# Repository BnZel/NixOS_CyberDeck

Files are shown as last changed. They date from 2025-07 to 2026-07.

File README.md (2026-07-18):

# NixOS Cyberdeck 
A cyberdeck project based on the **Intel Compute Stick** that is running **NixOS**. 

I'm excited that it has been [featured](https://www.canadarobotix.com/blogs/news/customer-spotlight-bnzels-cyberdeck-journey-part-4) on a store where I purchase most of my electronics at [CanadaRobotix](https://www.canadarobotix.com/).

NixOS Cyberdeck Logo

## Tests
cyberdeck_demo

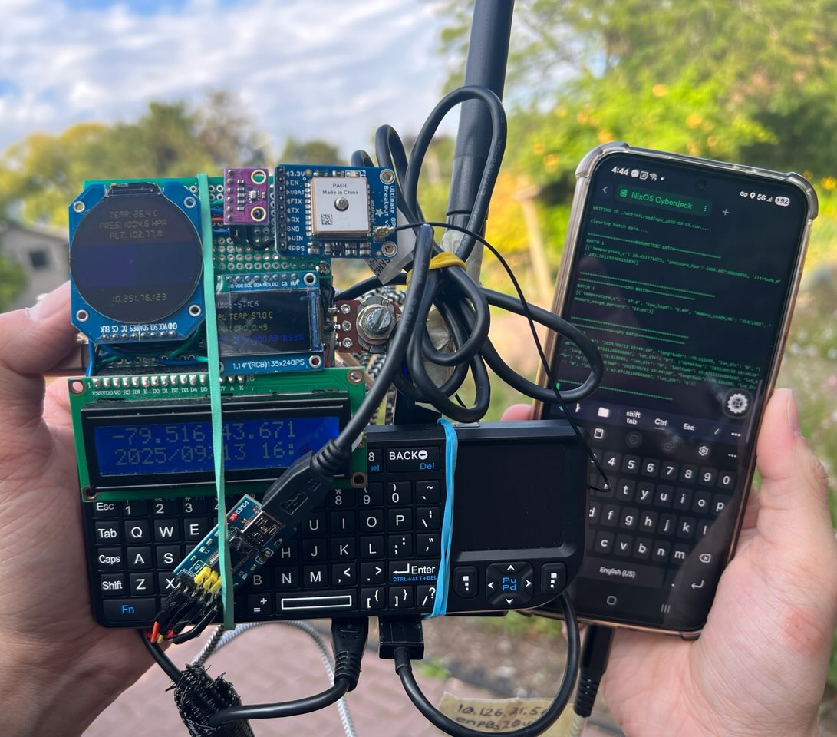
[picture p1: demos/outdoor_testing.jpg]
outdoor_testing


# Directory:
* [NixOS Database Analysis](./analysis/)
* [ESP32 Glove](./esp32_glove/)
* [Web Dashboard](./web_dashboard/)
* [Computer Aided Design](./cad/)

## Background

### Intel Compute Stick
The **[Intel Compute Stick (STK1AW32SC)](https://www.intel.com/content/www/us/en/products/sku/91065/intel-compute-stick-stk1aw32sc/specifications.html)** purpose was for media center applications, it has a convenient HDMI connector that can be directly plugged into any compatible monitor and TV.

Its main onboard specifications features:
* **4 CPU cores at 1.44 GHz**
* **32GB eMMC** and **2GB DDR3L-1600 RAM**
* **1 USB 2.0** and **1 USB 3.0** ports
* **MicroSDXC slot**

Although moderate in today standards, it is suitable enough for a *cyberdeck* based system.

### NixOS
The purpose of choosing **[NixOS](https://nixos.org/)** was because of its **reproducible system configurations** where it is easy to moveover to another machine. Allowing simple backups in scenarios where the cyberdeck were to encounter fatal issues.

The package manager makes it where the **build and development enviroments** can be properly separated and accessible without experiencing issues and interference with software tools. In my case, I can modify and/or activate environments based on what the cyberdeck needs to work on both hardware and software.

I have made several **blog posts** documenting my journey on the PC sticks:
1. [Discovering the Intel Compute Stick](https://bnzel.github.io/2024-08-03-Intel-Compute-Sticks/)
2. [Booting Ubuntu Server and NixOS onto the stick](https://bnzel.github.io/2024-08-07-ServerDeck-and-NixOS/)
3. [Breadboard prototyping the NixOS stick](https://bnzel.github.io/2025-04-07-NixOS-CyberDeck/)
4. [Latest iteration of the NixOS cyberdeck build](https://bnzel.github.io/2025-07-09-NixStick-Update/)

I list all software and hardware configurations, as well as documenting fixes issues too, though this README serves as a more thorough documentation. 

## Cyberdeck Introduction
This section will explain the *why?* and *how?* of my current build.

As I am limited by Intel's proprietary hardware, modifications are only on software tools, hardware addons, and the software written to run the hardware stack. 

### Hardware Addon

* **[Orico USB3.0 Hub with Gigabit Ethernet Converter](https://www.orico.shop/en/orico-usb30-hub-with-gigabit-ethernet-converter.html)** OR **[UNITEK H1117A02 4 Ports USB-A 3.0 Hub](https://www.canadacomputers.com/en/usb-hubs/260566/unitek-4-ports-usb-a-3-0-hub-h1117a02.html)** *(recommended as there is an external power supply to avoid pulling current from the deck itself)*
* **[Riitek Wireless Keyboard V3](http://www.riitek.com/product/221.html)**
* **USB Hub Voltage & Current Tester**
* **[AdaFruit FT232H (USB-C)](https://learn.adafruit.com/adafruit-ft232h-breakout)**
* **FTDI FT232RL USB to TTL adapter**

> At times the USB hub causes overvoltage and can crash the system when booting. Removing it before plugging it ensures a safe bootup. 

The **Orico USB hub** had conflicts between the ethernet port and the Intel's built-in wireless chip that created this issue:
```
iwlwifi 0000:01:00.0: Microcode SW error detected. Restarting 0x2000000
```
So in [configuration.nix](./configurations/configuration.nix):
```
  environment.etc."modprobe.d/iwlwifi.conf".text = ''
    options iwlwifi 11n_disable=1
    options iwlwifi power_save=0
  '';
```

There were other issues regarding the **5V/3A** adapter that I don't recall as I had to do alot of trial and error in **[hardware-configuration.nix](./configurations/hardware-configuration.nix)**:
```
boot.blacklistedKernelModules = ["i2c-designware-platform" "i2c-designware-core" "axp20x" "axp20x_i2c" "axp288_charger "];
```

### Architecture Overview
cyberdeck_architecture

### Custom Hardware
The **FT232H** is the main driver of the following components:
* **Displays**:
    * **GC9A01** (round display)
    * **ST7789** (square display)
    * **16x2 LCD** (rectangle display) and a **potentiometer** to adjust backlight
* **[BME280 (Barometric sensor)](https://www.bosch-sensortec.com/products/environmental-sensors/humidity-sensors-bme280/)**
* **[AdaFruit Ultimate GPS V3](https://learn.adafruit.com/adafruit-ultimate-gps)**
* **[74HC595 Shift Register](https://learn.adafruit.com/74hc595/overview)**

The **FTDI cable** is to power and receive serial communication with the **GPS**. The **GPS** provides a smooth **3.3V** to power the **BMP280** to avoid voltage spikes that may interfere the sensor accuracy.

The **BMP280** had encountered an error where the chip is not recognized. This was due to a **CS** pin issue from the **FT232H** that I was not able to pinpoint the reason. I switch it from **C7** to **D7**.

**GC9A01** is to display data from **BMP280**, **ST7789** to view the cyberdecks cpu: temperature, load, memory resource. The **LCD** shows date-time and **GPS** location. 

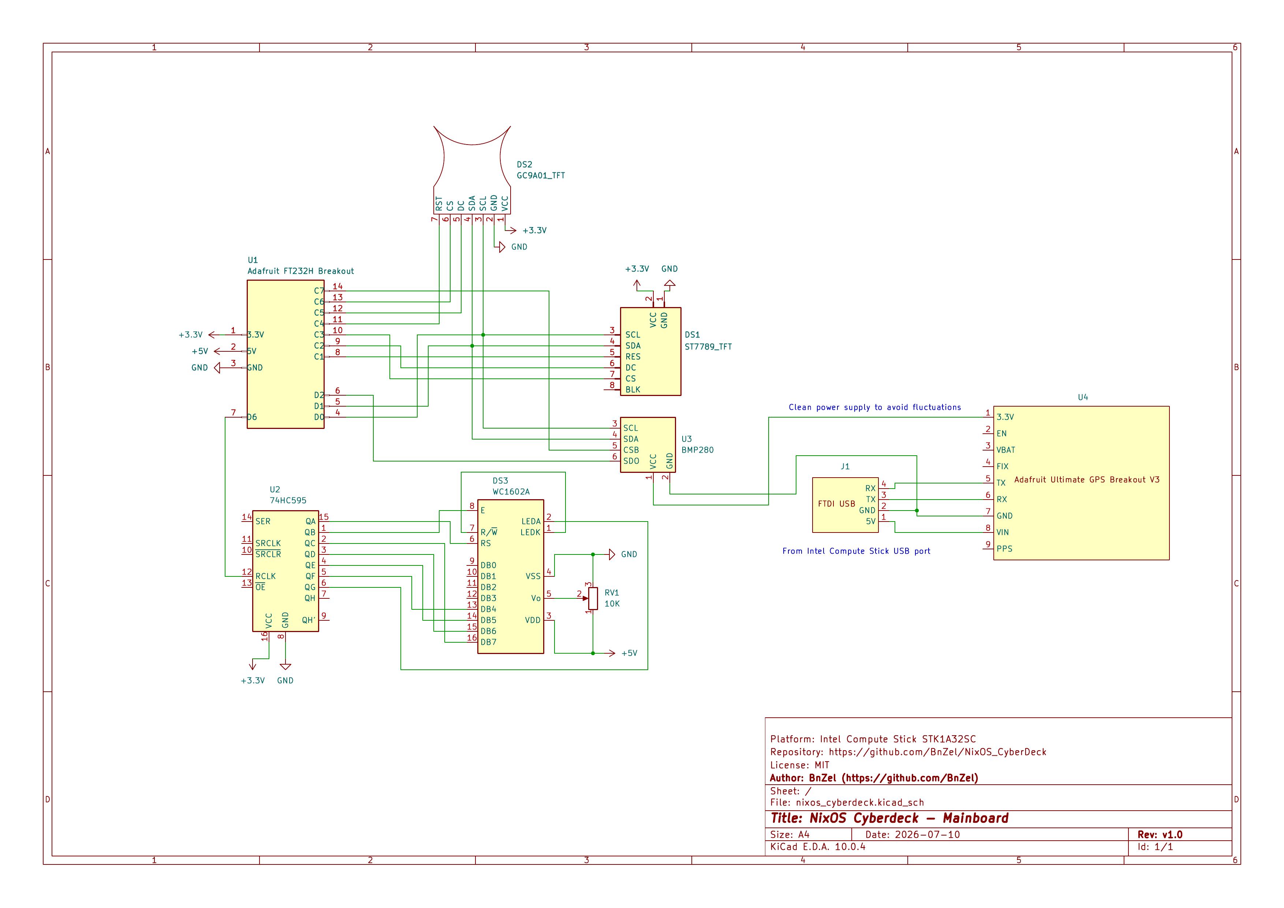
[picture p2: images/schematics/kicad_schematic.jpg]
kicad schematic
 

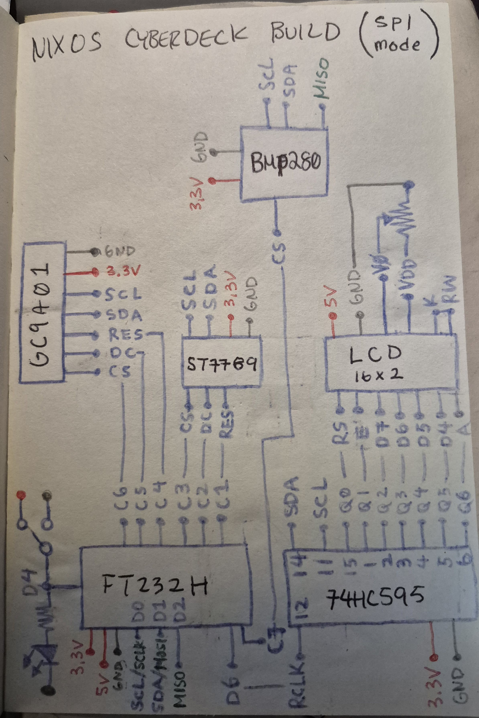
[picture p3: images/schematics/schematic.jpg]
schematic


A **SPST switch** in **D4** was suppose to be to activate a webcam stream but was not necessary for the moment.

In my blog post, I mentioned wanting a more compact design, so my approach was to make it stackable:

#### First Layer:
This were the FT232H sits, it will provide pins and **5V**, **3.3V**, **GND** pins to the second layer.

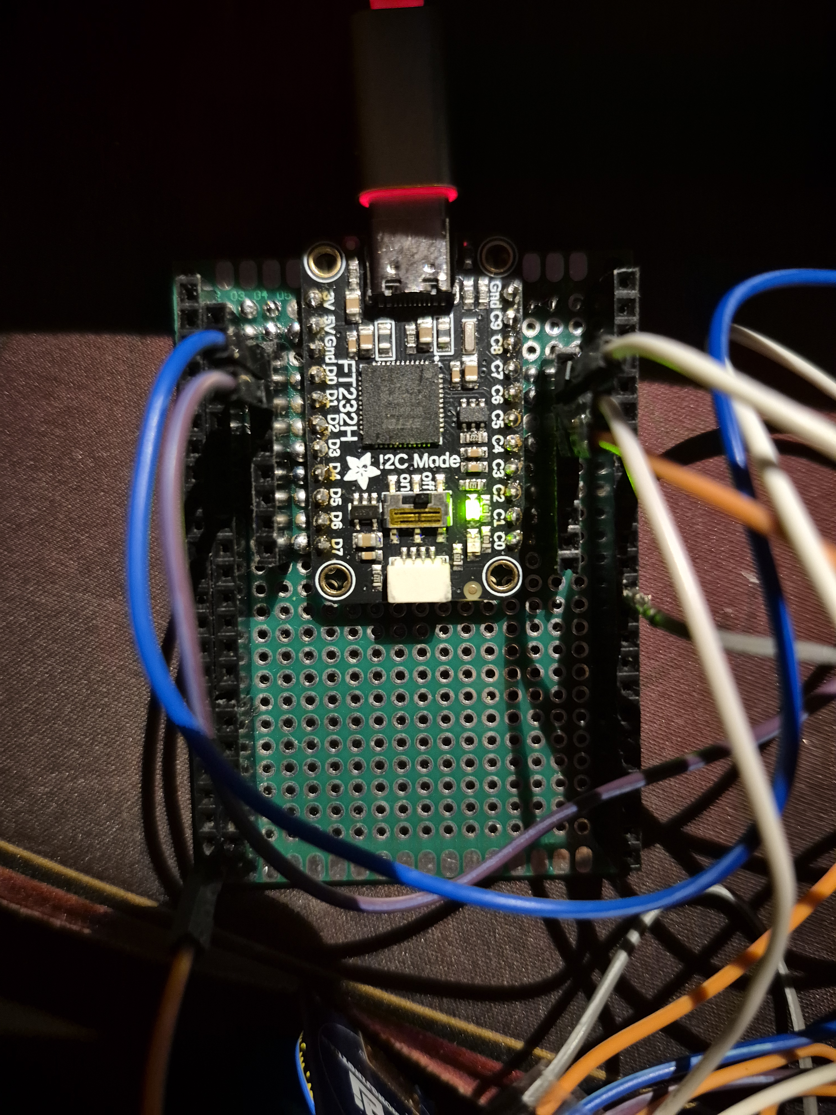
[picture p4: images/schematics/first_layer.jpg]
first layer


#### Second Layer:
All sensors and displays will sit here. There's another small protoboard above to give the BMP280 and GPS space.

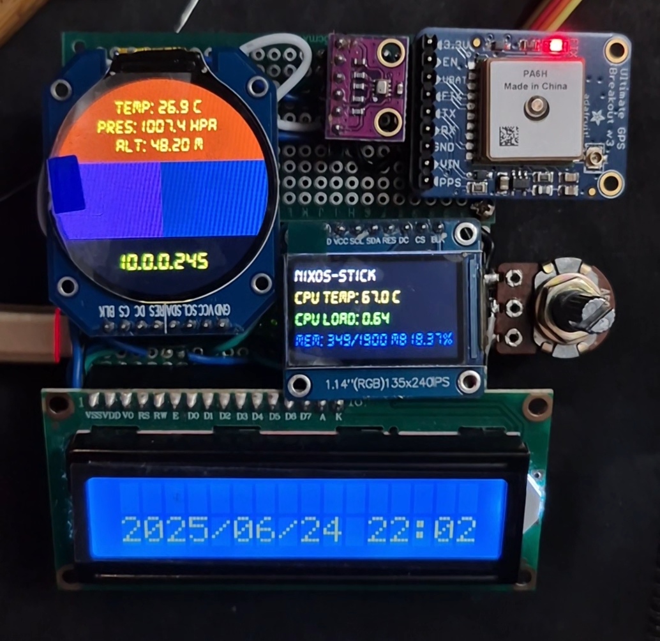
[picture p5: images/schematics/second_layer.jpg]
second layer


### Software
In the **[configurations.nix](./configurations/configuration.nix)** file:

Nix packages I use:
```
   environment.systemPackages = with pkgs; [
     wget
     htop
     fastfetch
     zsh
     oh-my-zsh
     git
     linux-firmware
     linux-wifi-hotspot
     tmux
     busybox
     cockpit
     libusb1
   ];
```
My mostly used tools are **zsh** for its autocomplete and highlighting features, **cockpit (runs on port 9090)** for a more graphical approach to my headless setup and to view system health, and **tmux** to view dmesg logs and starting scripts within one terminal.

Creating a separate Python environment in NixOS is different from other Linux distros, I came across this **[template](https://github.com/NixOS/nixpkgs/blob/49829a9adedc4d2c1581cc9a4294ecdbff32d993/doc/languages-frameworks/python.section.md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)** from their official **[Github](https://github.com/NixOS)** that I **[modified](./configurations/default.nix)**.

**OpenCV** was not used but can be useful for linking important **cpp .so** files:
```
LD_LIBRARY_PATH = lib.makeLibraryPath [ pkgs.stdenv.cc.cc ];
```
Addtional packages for the environment. **screen** to view serial data, **gcc** to compile C/C++ files for potential projects, **pkg-config** if linking more object files are needed:
```
packages = [ pkgs.screen pkgs.gcc pkgs.gnumake pkgs.pkg-config pkgs.openssl ];
```

[sanity_test.py](./software/sanity_test.py) is to check whether both the FT232H and FTDI cables are properly connected. Troubleshooting that first avoids assuming a USB hub issue.

FT232H runs on **[Adafruit_Blinka](https://github.com/adafruit/Adafruit_Blinka)** and at the moment, **adafruit-blinka** is not on nixpkgs so [requirements.txt](./software/requirements.txt) will do. Libraries for 75HC595 shift register, processing serial data for the FTDI, and displays will also be in the txt file.

#### [Custom Hardware Driver](./software/main.py)
```python

import board
from board import SCK, MOSI, MISO

import busio
import digitalio
from adafruit_rgb_display.st7789 import ST7789
from PIL import Image, ImageDraw, ImageFont

from adafruit_rgb_display.gc9a01a import GC9A01A

import adafruit_bmp280

import numpy as np
import cv2 as cv
import asyncio
import os

import time
import subprocess

import adafruit_character_lcd.character_lcd as character_lcd
import adafruit_74hc595

import wws_74hc165

import serial
import usb.core
import sys
import pynmea2
import datetime
import random

spi = busio.SPI(clock=SCK, MOSI=MOSI, MISO=MISO)

def init_display(disp,cs,dc,reset,rotate,w,h,x_off,y_off,BAUDRATE=24000000):
    CS_PIN = cs
    DC_PIN = dc
    RESET_PIN = reset
    display = disp(
        spi,
        rotation=rotate,
        width=w,
        height=h,
        x_offset=x_off,
        y_offset=y_off,
        baudrate=BAUDRATE,
        cs=digitalio.DigitalInOut(CS_PIN),
        dc=digitalio.DigitalInOut(DC_PIN),
        rst=digitalio.DigitalInOut(RESET_PIN)
    )
    return display

def rotation(display):
    height=0
    width=0
    if display.rotation % 180 == 90:
        height = display.width  # swap height/width to rotate it to landscape
        width = display.height
    else:
        width = display.width  # swap height/width to rotate it to landscape
        height = display.height

    return height, width

def draw_image(disp,width,height,fill=0):
    disp.fill(0)
    disp_image = Image.new("RGB", (width,height))
    disp_draw = ImageDraw.Draw(disp_image)

    return disp_image, disp_draw

async def bmp280_task():
#    if btn_toggle.value is False:
        gca_draw.rectangle((0, 0, disp_gc9a01.width, disp_gc9a01.height // 2 - 30), fill=(155, 50, 0))
        gca_txt_bmp_temp = "    Temp: {:.1f} C".format(bmp280.temperature) + "\nPres: {:.1f} hPa".format(bmp280.pressure) + "\n    Alt: {:.2f} M".format(bmp280.altitude)
        gca_draw.text(
            (disp_gc9a01.width // 2 - 70 , disp_gc9a01.height // 2 - 100),
            gca_txt_bmp_temp,
            font=gca_bmp_font,
            fill=(255, 255, 0),
        )
#        gca_draw.text(
#	    (disp_gc9a01.width//2-70, disp_gc9a01.height//2-100),
#	    f"{random.randint(0,100)}",
#	    font=gca_font,
#            fill=(255,255,0),
#        )
        disp_gc9a01.image(gca_image)

async def cam_task():
    if btn_toggle.value is True:
        ret,frame = cap.read()

        if not ret:
            print("Can't receive frame (stream end?). Exiting...")
            os._exit(1)

        resize = cv.resize(frame, (disp_gc9a01.width, disp_gc9a01.height), interpolation=cv.INTER_AREA)
        rgb = cv.cvtColor(resize, cv.COLOR_BGR2RGB)
        pil = Image.fromarray(rgb)
        disp_gc9a01.image(pil)

async def async_main():
   # await asyncio.gather(bmp280_task(),cpu_task(),cam_task(),gps_task())
   await asyncio.gather(bmp280_task(),cpu_task(),gps_task())

async def cpu_task():
    st7789_draw.rectangle((0, 0, width, height), outline=0, fill=0)

    # REFERENCE: https://unix.stackexchange.com/questions/119126/command-to-display-memory-usage-disk-usage-and-cpu-load
    hostname = subprocess.check_output("hostname",shell=True).decode("utf-8")
    cpu_temp = subprocess.check_output("cat /sys/class/thermal/thermal_zone1/temp |  awk '{printf \"CPU Temp: %.1f C\", $(NF-0) / 1000}'",shell=True).decode("utf-8")
    cpu_load = subprocess.check_output("top -bn1 | grep load | awk '{printf \"CPU Load: %.2f\", $(NF-2)}'",shell=True).decode("utf-8")
    mem = subprocess.check_output("free -m | awk 'NR==2{printf \"Mem: %s/%s MB %.2f%%\", $3,$2,$3*100/$2 }'",shell=True).decode("utf-8")

    st7789_draw.text((x,y+10),hostname,font=st7789_font, fill="#FFFFFF")
    st7789_draw.text((x,y+40),cpu_temp,font=st7789_font, fill="#FFFF00")
    st7789_draw.text((x,y+70),cpu_load,font=st7789_font, fill="#00FF00")
    st7789_draw.text((x,y+100),mem,font=st7789_font, fill="#000FF0")

    # display it by 90 deg
    disp_st7789.image(st7789_image)

async def gps_task():

#    lcd.message = "Hello World!"
#    print(lcd.message)

    # TODO: Find a way to retrieve FTDI name, locate the port
    #       and use that. Check if it is open, otherwise continue 
    with serial.Serial("/dev/ttyUSB1", 9600, timeout=1) as ser:

        data = ser.readline().decode('ascii', errors='replace')
        dt = datetime.datetime.now().strftime("%Y/%m/%d %H:%M")

        if(data[0:6] == "$GPRMC"):
            lcd.clear()

            gps_data = pynmea2.parse(data)

            lon = gps_data.longitude
            lat = gps_data.latitude

            lcd.message = "Lon:{0} Lat:{1}".format(lon,lat)
            print(lcd.message)

        lcd.message = "\n{0}".format(dt)

if __name__ == "__main__":
    # REMINDER: THIS SCRIPT IS IN ONLY SPI MODE!
    #           (SINCE THE FT232H UART/MPSSE OPERATES IN ONE SPECIFIC MODE)

    # -----74HC165 IS INPUT ONLY-----
    #_74hc165_isr_latch = board.D5
    #_74hc165_isr = wws_74hc165.ShiftRegister74HC165(spi, _74hc165_isr_latch, 1)

    # -----74HC595 IS OUTPUT ONLY-----
    _74hc595_isr_latch = digitalio.DigitalInOut(board.D6)
    _74hc595_isr = adafruit_74hc595.ShiftRegister74HC595(spi, _74hc595_isr_latch, 1)

    # connecting LCD to 74HC595 
    lcd_rs = _74hc595_isr.get_pin(0)
    lcd_en = _74hc595_isr.get_pin(1)
    lcd_d7 = _74hc595_isr.get_pin(2)
    lcd_d6 = _74hc595_isr.get_pin(3)
    lcd_d5 = _74hc595_isr.get_pin(4)
    lcd_d4 = _74hc595_isr.get_pin(5)

    lcd_backlight = _74hc595_isr.get_pin(6)

    lcd_columns = 16
    lcd_rows = 2

    lcd = character_lcd.Character_LCD_Mono(lcd_rs, lcd_en, lcd_d4, lcd_d5, lcd_d6, lcd_d7, lcd_columns, lcd_rows, lcd_backlight)
    lcd_backlight.value = True
    lcd.message = "BOOTING\nUP..."

    # clear old outputs for incoming ones
    subprocess.run(["clear"])

    # switch for camera mode for round display
#    btn_toggle = digitalio.DigitalInOut(board.D4)
#    btn_toggle.direction = digitalio.Direction.INPUT

    # list connected USB devices
    print("ls /dev/video* : ",subprocess.check_output("ls /dev/video* | grep -oP '/dev/video\d+' | tr '\n' ' ' | sed 's/ $//'",shell=True))
    print("ls /dev/ttyUSB* : ",subprocess.check_output("ls /dev/ttyUSB* | grep -oP '/dev/ttyUSB\d+' | tr '\n' ' ' | sed 's/ $//'",shell=True))

    # camera check
#    cap = cv.VideoCapture(-1)
#    if not cap.isOpened():
#        print("Cannot open camera...")
#    cap.set(cv.CAP_PROP_FPS,30)

    # barometer setup for round display
    bmp280_cs = digitalio.DigitalInOut(board.D7)
    bmp280 = adafruit_bmp280.Adafruit_BMP280_SPI(spi, bmp280_cs)
    bmp280.sea_level_pressure = 1017.0
    gca_bmp_font = ImageFont.truetype('./DS-DIGIT.TTF',20)

    # ----------------set up round display ----------------
    disp_gc9a01 = init_display(GC9A01A,board.C6,board.C5,board.C4,180,240,240,0,0)
    gca_image, gca_draw = draw_image(disp_gc9a01,disp_gc9a01.width,disp_gc9a01.height)

    gca_draw.rectangle((0, 0, disp_gc9a01.width, disp_gc9a01.height // 2 - 30), fill=(155, 50, 0))                          # upper rectangle
    gca_draw.rectangle((0, 90, disp_gc9a01.width // 2, disp_gc9a01.height // 10 + 150), fill=(105, 50, 150))                # left rectangle
    gca_draw.rectangle((120, 90, disp_gc9a01.width // 2 + 150, disp_gc9a01.height // 10 + 150), fill=(10, 50, 100))         # right rectangle

    gca_font = ImageFont.truetype('./DS-DIGIT.TTF',25)
    gca_txt_ip = subprocess.check_output("ip -4 addr | grep -oP '(?<=inet\s)\d+(\.\d+){3}' | grep -v '127\.0\.0\.1'",shell=True).decode("utf-8")
    gca_draw.text(
        (disp_gc9a01.width // 2 - 50 , disp_gc9a01.height // 2 + 70),
        gca_txt_ip,
        font=gca_font,
        fill=(255, 255, 0),
    )
    disp_gc9a01.image(gca_image)
    # ------------------------------------------------------

    # ---------------- set up tft display ----------------
    x = 0
    y = -2
    disp_st7789 = init_display(ST7789,board.C3,board.C2,board.C1,90,135,240,53,40)
    height,width = rotation(disp_st7789)
    st7789_image, st7789_draw = draw_image(disp_st7789,width,height)
    st7789_font = ImageFont.truetype('./DS-DIGIT.TTF',23)
    # ------------------------------------------------------

    lcd.clear()

    # gracefully exit when CTRL+C
    try:
        while True:
            asyncio.run(async_main())

    # offload camera, lcd, and exit
    except KeyboardInterrupt:
 #       cap.release()
        lcd.clear()
        lcd.backlight = False
        os._exit(1)
        print("\nCancelled...")
```

## Latest Setup

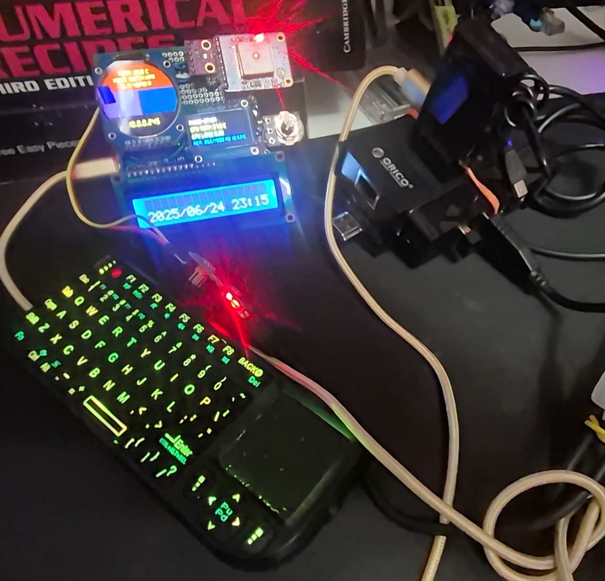
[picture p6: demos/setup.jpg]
setup


case setup

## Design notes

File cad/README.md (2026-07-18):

# Hardware Designs

A reference page to document iterations of **schematic**, **PCB** and **CAD** designs. 

Tools used are **[KiCAD](https://www.kicad.org/)** and **[FreeCAD](https://www.freecad.org/)**

### [Version 1](./v1/)
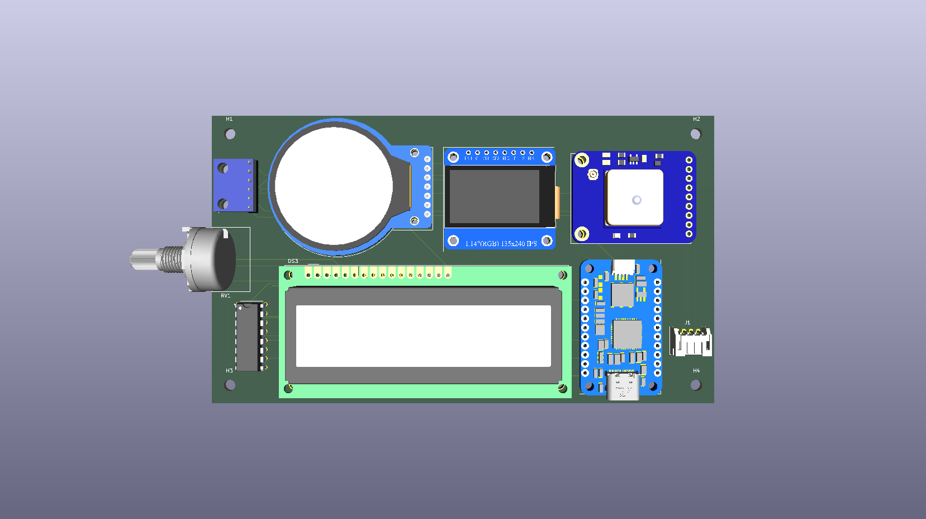
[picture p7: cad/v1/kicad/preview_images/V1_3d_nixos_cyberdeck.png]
preview model


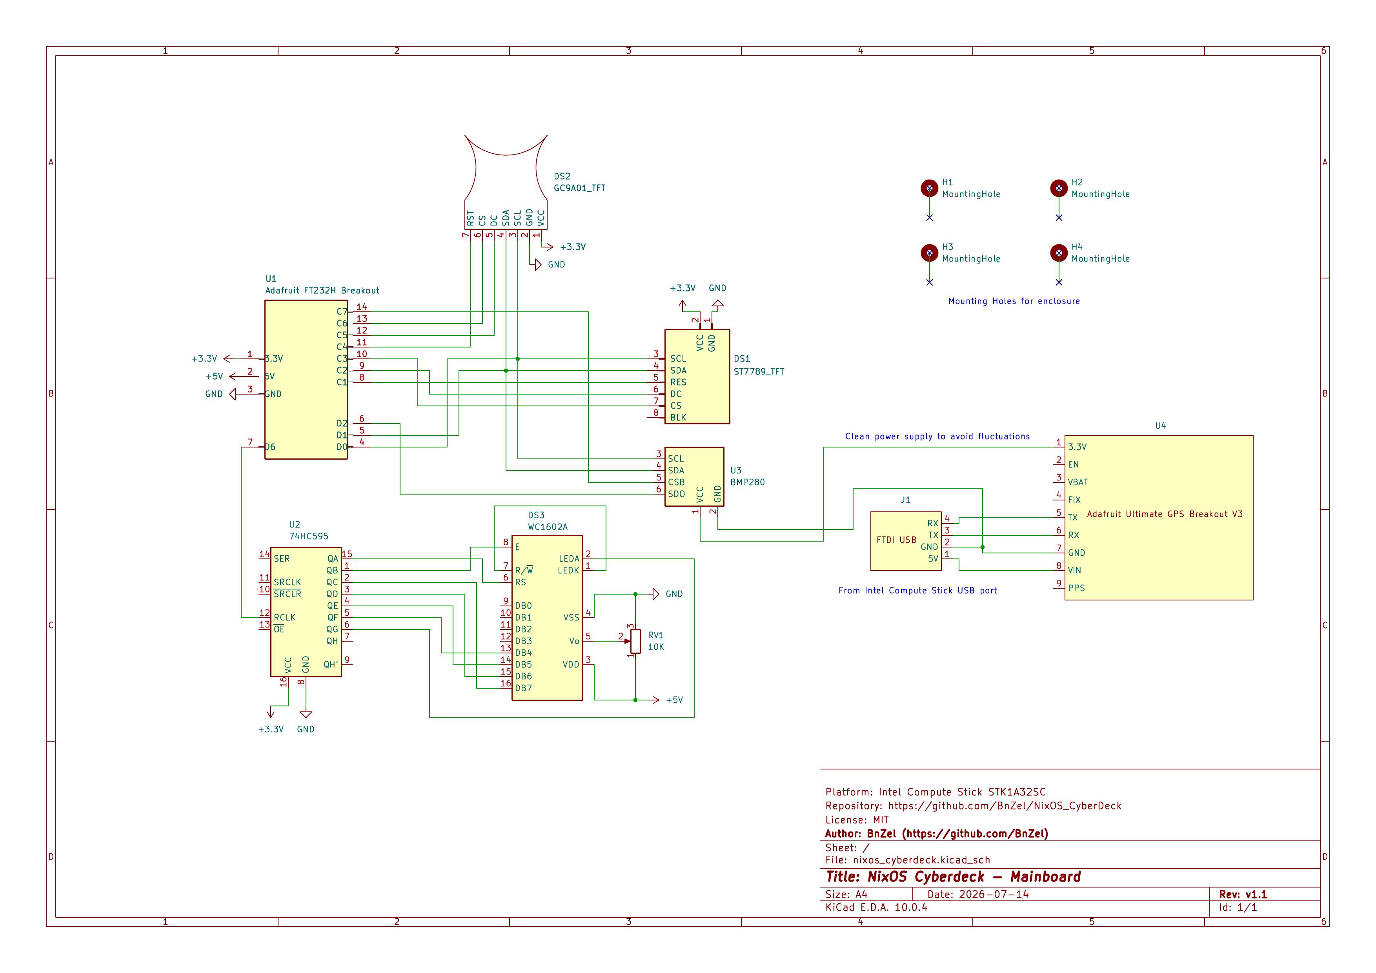
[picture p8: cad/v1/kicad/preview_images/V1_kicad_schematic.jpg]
preview schematic


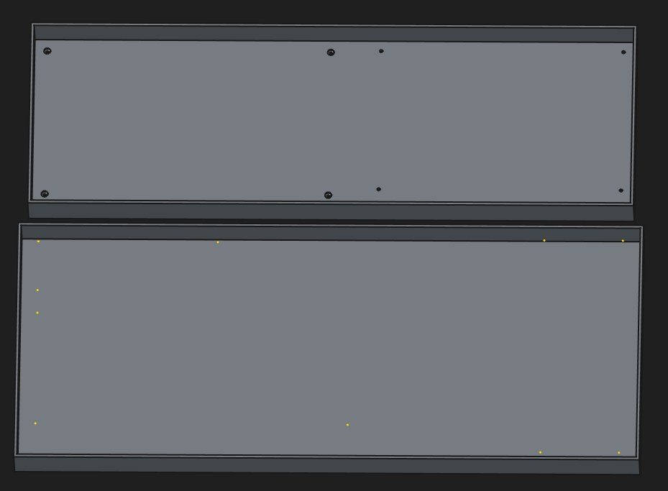
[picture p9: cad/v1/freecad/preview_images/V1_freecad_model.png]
preview case


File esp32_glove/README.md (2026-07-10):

# ESP32 Glove

A custom sensor glove based on the [Adafruit ESP32 Feather Huzzah](https://learn.adafruit.com/adafruit-huzzah32-esp32-feather?view=all) that is connected to the cyberdecks TCP server. It is programmed in **[MicroPython](https://micropython.org/)**.

The glove is based on the [Potentiometer Glove Model](https://www.thingiverse.com/thing:2782111) on Thingiverse.

I have made posts on my blog documenting my two iterations of the glove:
* [Sensor Glove V1](https://bnzel.github.io/2024-11-13-Crude-Sensor-Glove/)
* [Sensor Glove V2](https://bnzel.github.io/2025-07-10-Sensor-Glove-V2/)

### Demo
esp32 demo

### Hardware
* **[Adafruit ESP32 Feather Huzzah](https://learn.adafruit.com/adafruit-huzzah32-esp32-feather?view=all)**
* **[Potentiometer Glove Model](https://www.thingiverse.com/thing:2782111)**
* **1.3" I2C OLED (SSD1306)**
* **MPU9250**
* **5x Rotary Potentiometers**

### Software
#### Libraries:
* [SSD1306 Library](https://github.com/Eivs/micropython-ssd1306-oled-1.3-drivers)
* [MPU9250 Library](https://github.com/tuupola/micropython-mpu9250)
#### Code
* **[Firmware](./firmware/)**
* **[TCP Server in C](./glove_server/)**

### Resources
* [map() function in Arduino](https://docs.arduino.cc/language-reference/en/functions/math/map/)
* [Exponential Smoothing](https://en.wikipedia.org/wiki/Exponential_smoothing)

### Diagram 
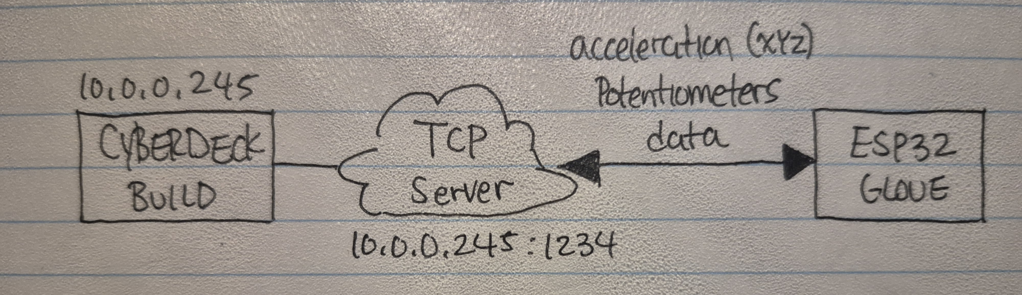
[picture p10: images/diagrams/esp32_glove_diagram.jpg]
diagram

*this is part of the [cyberdeck architecture diagram](../images/diagrams/cyberdeck_architecture.jpg)*
### Schematic
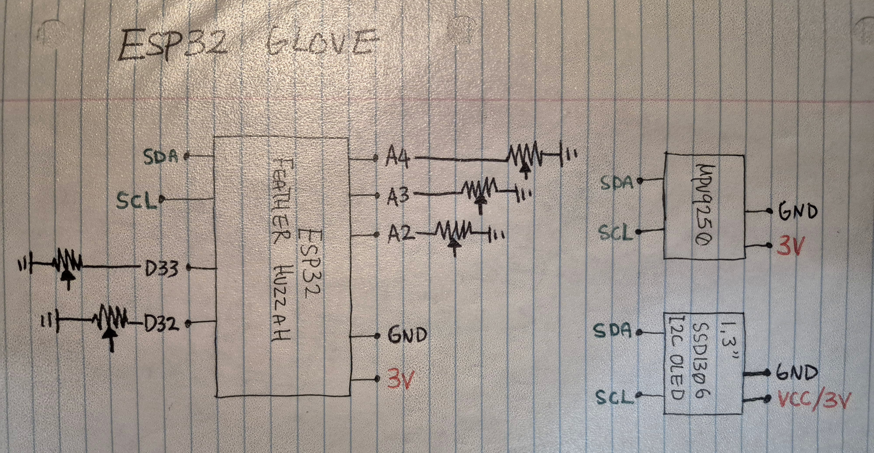
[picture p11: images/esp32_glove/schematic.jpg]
schematic


### Sketch
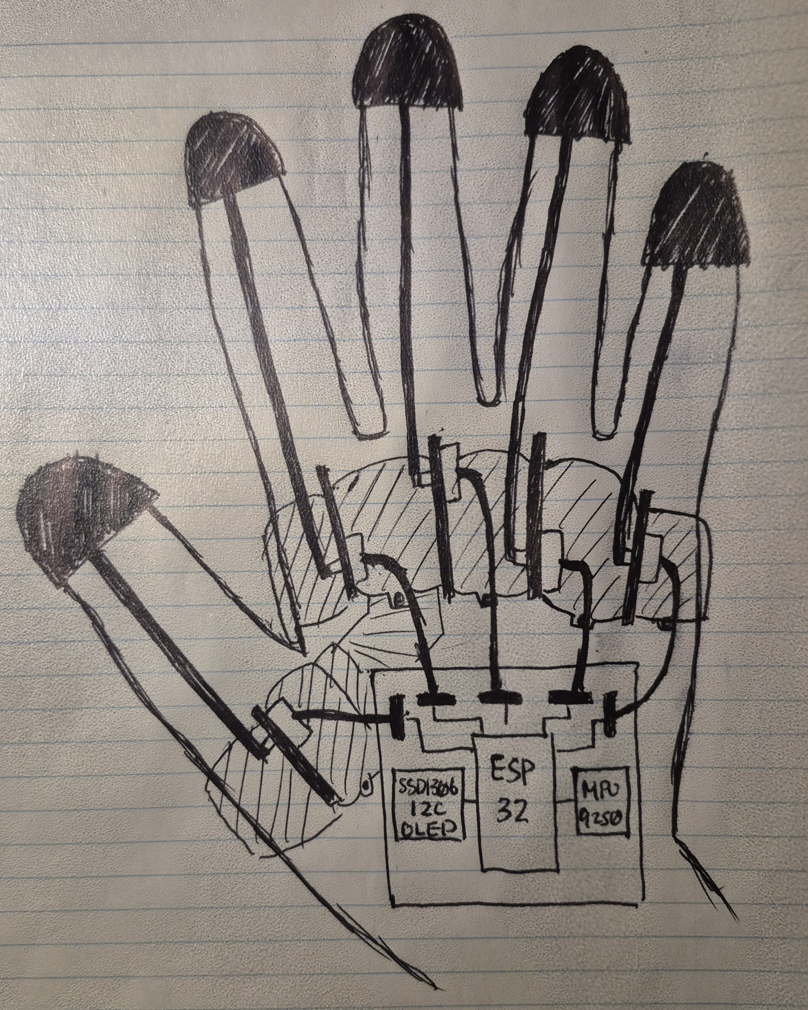
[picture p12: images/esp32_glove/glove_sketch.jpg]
sketch


### Formulas

#### Affine Transformation
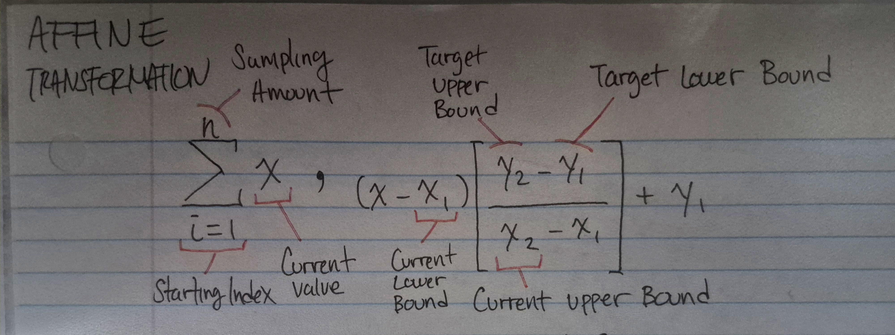
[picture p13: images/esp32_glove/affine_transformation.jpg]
affine


```python
def map_(adc_pin, id, from_low=0, from_high=0, to_low=0, to_high=0, sample=24, smooth=False):
    x_ = adc_pin.read()
    if from_high == 0 and to_high == 0:
        return x_
    else:
        if sample > 1:
            sum_ = 0
            for i in range(sample):
                sum_ += adc_pin.read()
            x_ = sum_ // sample
        
        # NOTE: unusual behaviour where some readings
        #       slowly reduce and others do not respond
        if smooth:
            if id not in pot_ID:
                pot_ID[id] = x_
            x_ = smoothing(x_, pot_ID[id])
            pot_ID[id] = x_

    z = (x_ - from_low) * (to_high - to_low) // (from_high - from_low) + to_low 
    return z
```

#### Exponential Smoothing
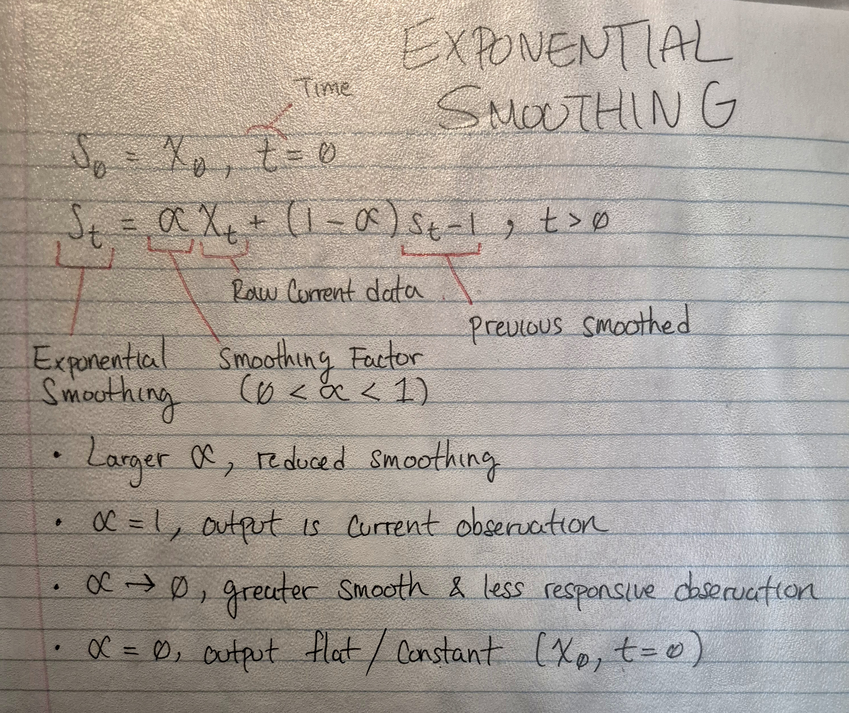
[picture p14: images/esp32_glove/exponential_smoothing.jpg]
exponential

```python
def smoothing(s0, prev_s_t, alpha=0.1):
    # 0 < alpha < 1
    if alpha >= 0 and alpha <= 1:
        prev_s_t = alpha * s0 + (1-alpha) * prev_s_t
        return int(prev_s_t)
    return s0
```
### Applications
* ### [Servo Controller](./servo_controller/)
A demo showcasing remote control of servos. 

servo controller demo

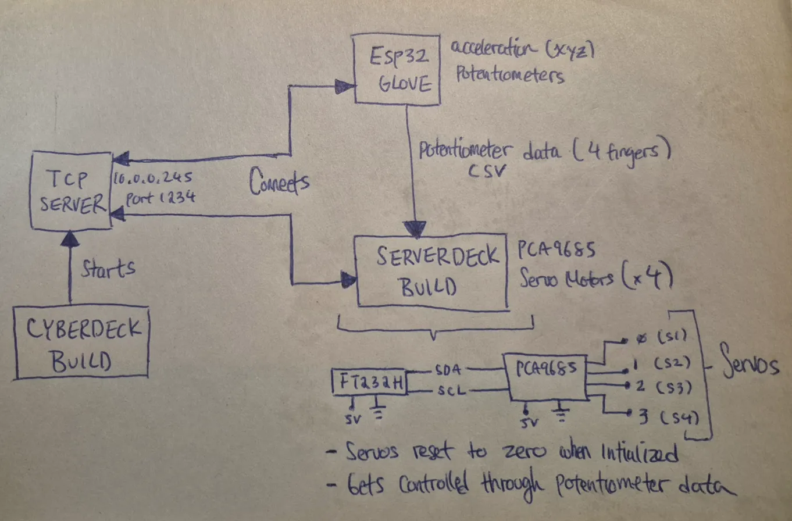
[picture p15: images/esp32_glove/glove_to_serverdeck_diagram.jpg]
glove to serverdeck diagram


The **[SERVERDECK BUILD](https://bnzel.github.io/2024-08-07-ServerDeck-and-NixOS/)** block refers to my very first cyberdeck build but this can be interchangable with any client.

### Software
* **[main.py](./servo_controller/main.py)**
* **[requirements.txt](./servo_controller/requirements.txt)**

### Hardware
* **PCA9685**
* **DC Servo Motors (x4)**

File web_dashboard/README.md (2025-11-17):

# Web Dashboard
A remote dashboard that runs the startup script on the cyberdeck and displays sensor data 

> startup script is different from main as it does not log data and sends JSON data to the dashboard

Using a **ThinkCentre M700** running **[Proxmox VE](https://www.proxmox.com/en/)**. An **LXC container** running **Ubuntu 25.04 with 2GB memory and 1GB swap**

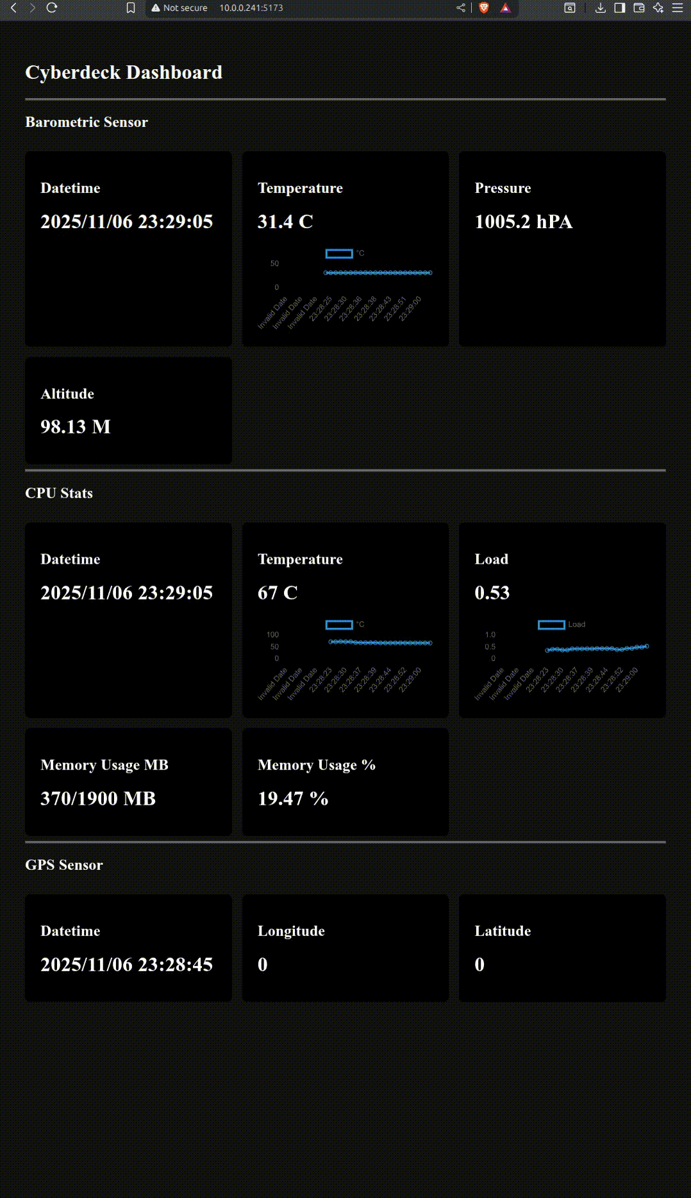
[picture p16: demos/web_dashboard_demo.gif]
dashboard


### Resources
* **[Svelte and Flask Dashboard Tutorial](https://testdriven.io/blog/flask-svelte/)**
* **[Paramiko Python SSH Tutorial](https://www.devdungeon.com/content/python-ssh-tutorial#toc-3)**

### Software
* **[Proxmox](https://www.proxmox.com/en/)**
* **[Test Script](./test.py)**
* **[Frontend](./frontend)**
* **[Backend](./backend)**

#### Frontend
* **[Svelte](https://svelte.dev/)**
* **SvelteKit**

#### Backend
* **[Flask](https://flask.palletsprojects.com/en/stable/)**
* **JSON**
* **[Paramiko](https://www.paramiko.org/)**

### Hardware
* **Lenovo ThinkCentre M700**

### Diagrams

#### Proxmox Web Directory
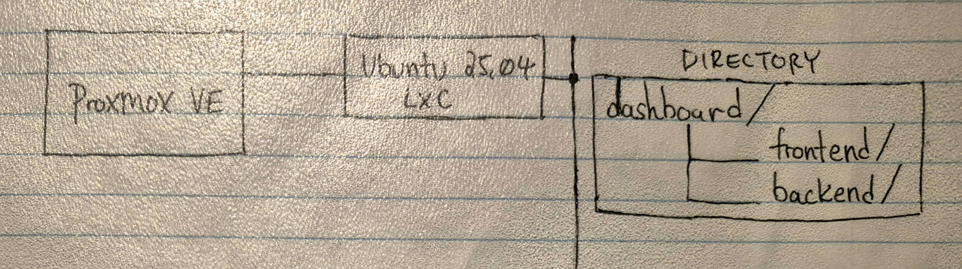
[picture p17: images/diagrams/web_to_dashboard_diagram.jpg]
web to cybedeck


#### How Proxmox Interacts With The Cyberdeck
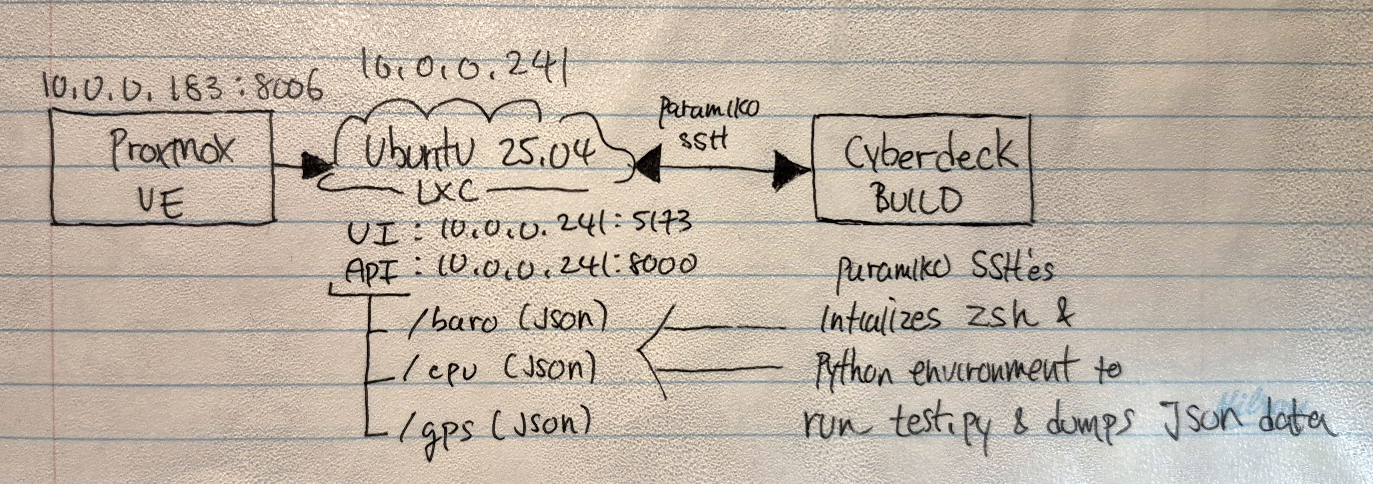
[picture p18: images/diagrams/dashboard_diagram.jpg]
dashboard


### Startup
```
cd web_dashboard/
npm install
npm run dev  
```

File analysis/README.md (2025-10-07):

# NixOS Database Analysis
This is a separate **Intel Compute Stick** to perform data analysis on the [NixOS Cyberdeck](../README.md). The purpose is to have a **portable embedded database** to store and process data (CPU, GPS, Barometric sensors). While this setup can be installed on the same device it's best to differentiate the task to avoid confusion and overhead.

## Overview
nixexp_architecture

## Setup
* **[analysis.ipynb](./analysis.ipynb)**
* **cyberdeck.db**
* **[default.nix](./default.nix)**
* **[requirements.txt](./requirements.txt)**

In **default.nix** the following packages will be installed:
```
    # main data analysis tools
    pythonPackages.pandas
    pythonPackages.matplotlib
    pythonPackages.numpy
    pythonPackages.requests

    # optional but recommended
    packages = [ pkgs.screen pkgs.gcc pkgs.gnumake pkgs.pkg-config pkgs.openssl ];

    # needed to load jupyter notebook server
    LD_LIBRARY_PATH = lib.makeLibraryPath [ pkgs.stdenv.cc.cc ];
```
> The Jupyter NixOS package currently has issues, a post made in this [github issue](https://github.com/NixOS/nixpkgs/issues/255923) suggested to use the pip environment to install Jupyter. 

Python packages that aren't avaliable in Nix packages can be installed through ```pip install -r requirements.txt```:
* **GPS:** **[Geopandas](https://geopandas.org/en/stable/)** and related libraries
* **[DuckDB](https://duckdb.org/)**

### **DuckDB**:
Tables are already made for each hardware component.

#### Tables
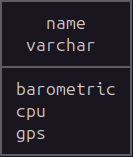
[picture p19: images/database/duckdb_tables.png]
duckdb_tables


#### Barometric Table
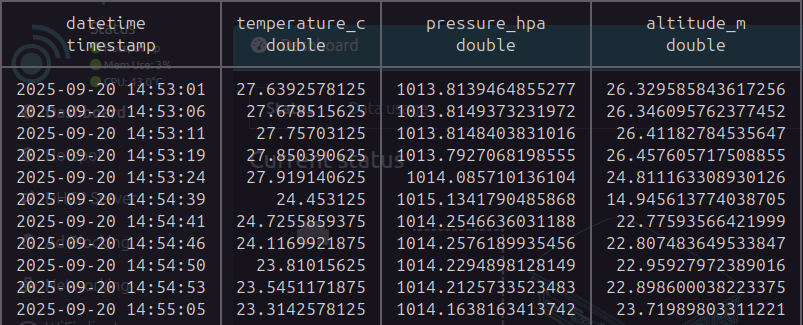
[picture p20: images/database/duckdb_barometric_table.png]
duckdb_barometric


#### CPU Table
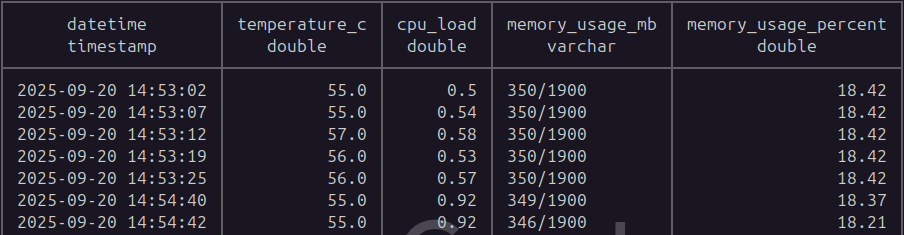
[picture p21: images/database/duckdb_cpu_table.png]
duckdb_cpu


#### GPS Table
Filtered for values that aren't non-zeroes. **SPATIAL** extension is needed to display the **lon_lat_geometry** column.
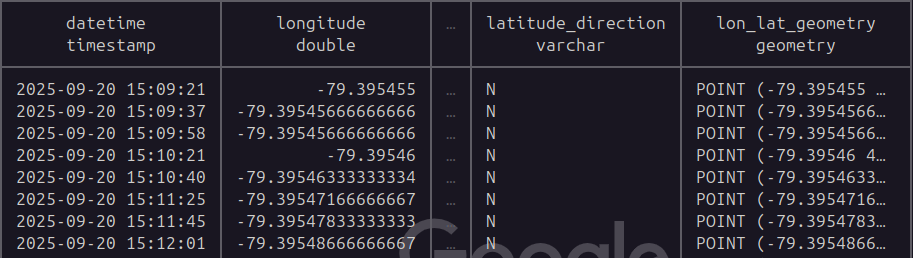
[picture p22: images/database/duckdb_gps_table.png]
duckdb_gps


### **Jupyter Notebook**
Can be used as reference.
### Geopandas
GPS points being plotted 

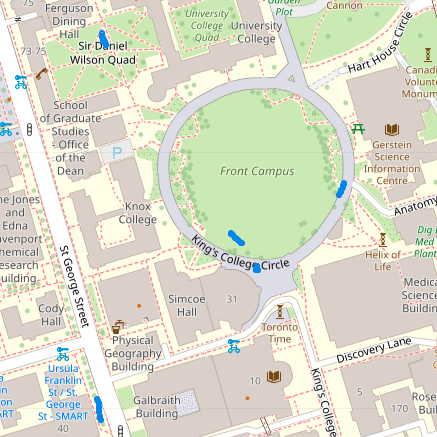
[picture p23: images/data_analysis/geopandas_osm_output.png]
geopandas_osm_output


### Matplotlib
Monitoring hardware usage over time. 
#### Barometric Plot
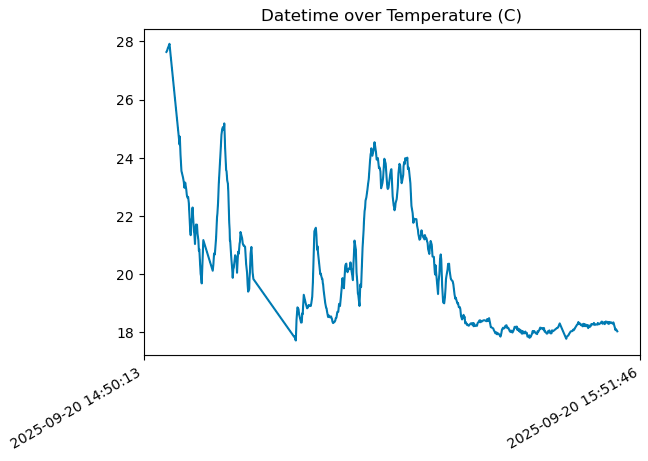
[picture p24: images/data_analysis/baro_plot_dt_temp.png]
baro_dt_temp


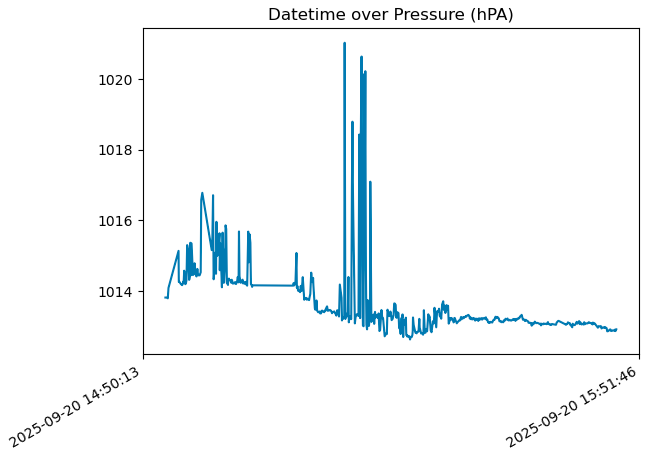
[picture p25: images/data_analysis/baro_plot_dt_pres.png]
baro_dt_pres


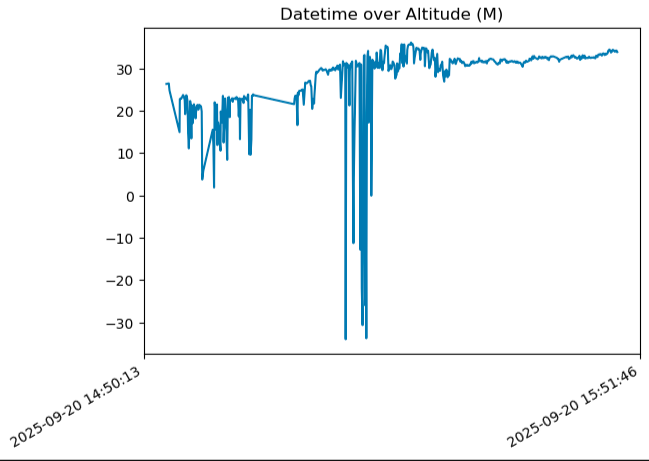
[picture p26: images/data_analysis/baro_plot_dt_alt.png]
baro_dt_alt


#### CPU Plot
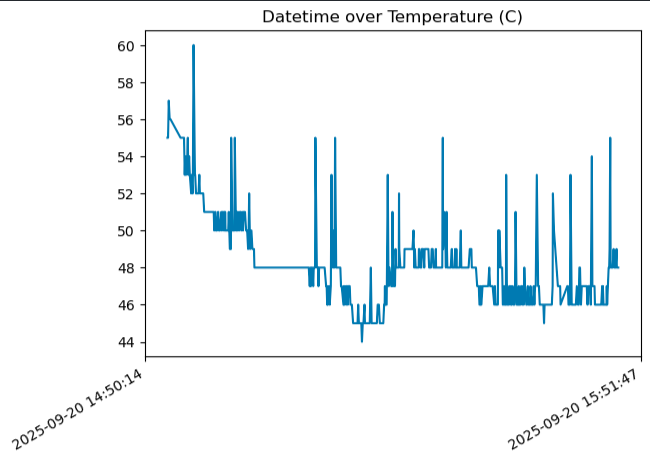
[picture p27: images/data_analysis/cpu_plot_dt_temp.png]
cpu_dt_temp


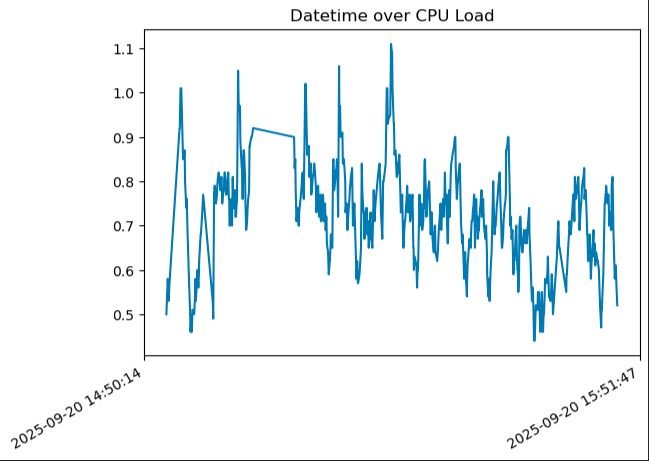
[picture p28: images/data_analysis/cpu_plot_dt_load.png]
cpu_dt_load


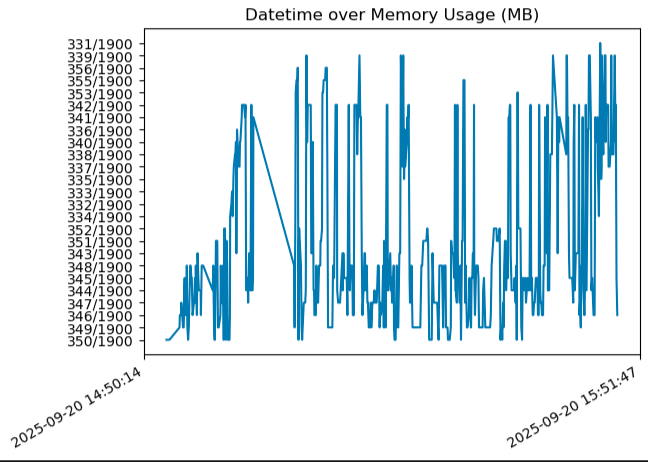
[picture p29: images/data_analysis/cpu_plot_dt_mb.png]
cpu_dt_mb


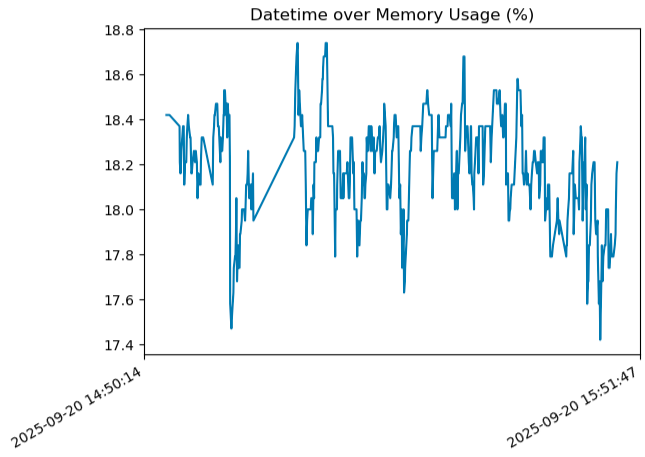
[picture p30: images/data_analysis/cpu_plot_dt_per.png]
cpu_dt_per


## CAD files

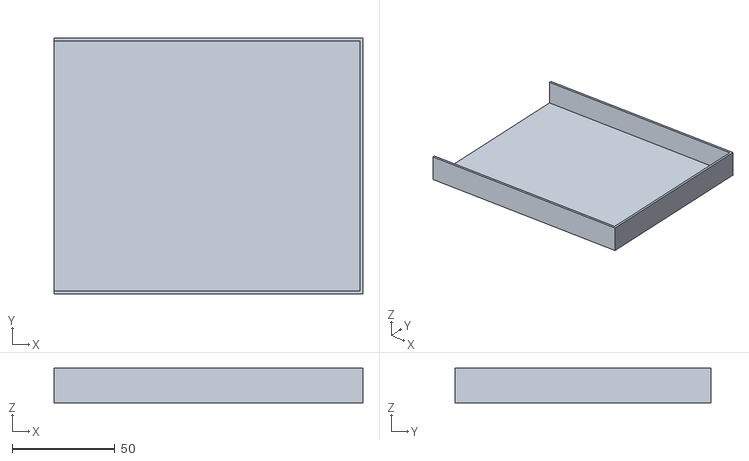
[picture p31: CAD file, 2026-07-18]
cad/v1/freecad/stls/separate_prints/cyberdeck_case_bottom_right.stl
150.7 x 125.0 x 17.0

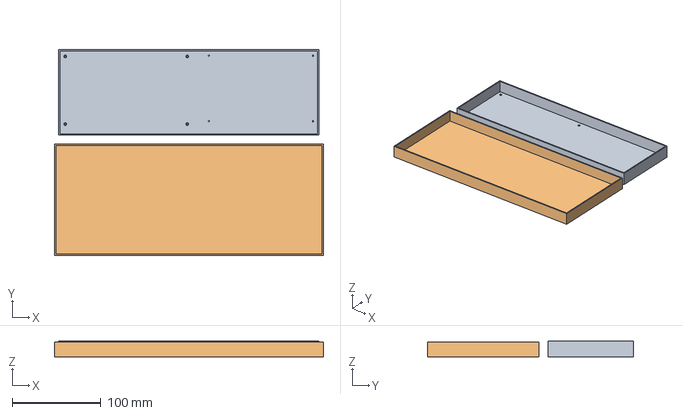
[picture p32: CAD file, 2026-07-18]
cad/v1/freecad/V1_nixos_cyberdeck.FCStd
302.5 x 231.3 x 17.9 mm
Body_TOP_COVER
Body_BOTTOM_COVER

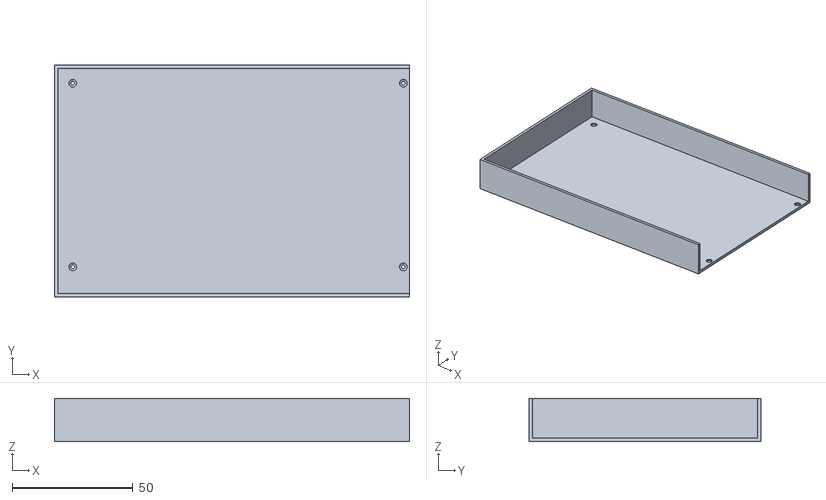
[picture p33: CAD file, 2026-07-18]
cad/v1/freecad/stls/separate_prints/cyberdeck_case_top_left.stl
147.2 x 96.2 x 17.9

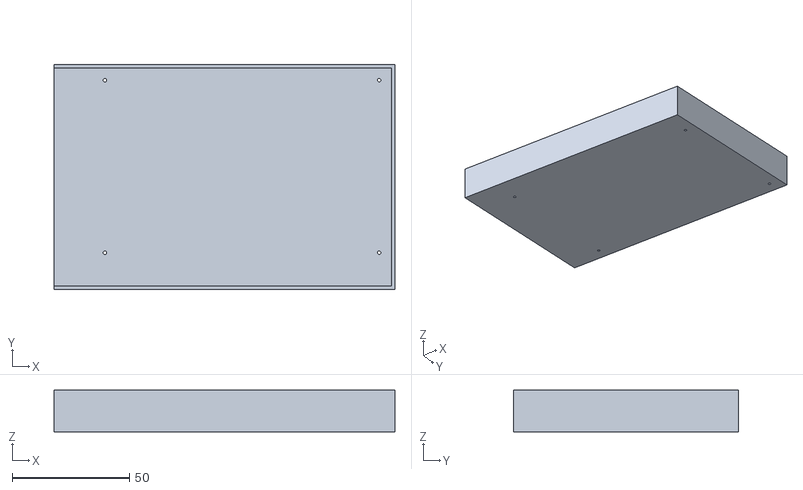
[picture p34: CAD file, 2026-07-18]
cad/v1/freecad/stls/separate_prints/cyberdeck_case_top_right.stl
145.7 x 96.2 x 17.9

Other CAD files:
cad/v1/freecad/stls/separate_prints/cyberdeck_case_bottom_left.stl
cad/v1/freecad/stls/V1_nixos_cyberdeck.stl

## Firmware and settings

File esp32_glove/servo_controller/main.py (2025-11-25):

'''
REFERENCES:
    - https://github.com/jefmenegazzo/mpu-i2c-drivers-python

    - https://github.com/adafruit/Adafruit_CircuitPython_PCA9685/blob/main/examples/pca9685_servo.py

    - https://github.com/pyenv/pyenv?tab=readme-ov-file#installation
'''

from curses.ascii import isdigit
import dataclasses
from hashlib import sha1
import time, socket
import board, busio, digitalio

from adafruit_servokit import ServoKit
import adafruit_pca9685, adafruit_motor.servo

from adafruit_pca9685 import PCA9685
from adafruit_motor import servo

from mpu9250_jmdev.registers import *
from mpu9250_jmdev.mpu_9250 import MPU9250


def init_servos(num_servos=15):
    '''
    initializes servos connected to PCA9685
    '''
    s = [0] * num_servos
    if num_servos <= 0:
        return s

    for i in range(num_servos):
        s[i] = servo.Servo(pca.channels[i])
        s[i].angle = 0
        print(f"Servo {i} angle: {s[i].angle}")

    print(f"Number of servos intialized: {len(s)}")
    return s


def control(servos):
    '''
    Control servo angles
    and limit their angles (0 - 180)
    '''
    for i in range(len(servos)):
        servo[i].angle = limit(servos[i])

    print(f"(A3) S0: {servo[0].angle} | (A4) S1: {servo[1].angle} | (D32) S2: {servo[2].angle} | (D33) S3: {servo[3].angle}")


def limit(angle):
    if angle >= 180:
        angle = 180
        return angle
    elif angle <= 0:
        angle = 0
        return angle
    else:
        return angle
    

def connect(host="10.0.0.245",port=1234):
    '''
    Connect to NixStick TCP server port 1234
    '''

    with socket.socket(socket.AF_INET, socket.SOCK_STREAM) as client:
        client.connect((host,port))

        ack = client.recv(4096)
        print(f"Server acknowledgment: {ack.decode().strip()}")
        
        while True:           
            client.send("SERVERDECK".encode())
            recv_ = client.recv(4096)

            # strip csv and unpack data into 
            # 4 active servos on PCA9685:
            #   s1 => index finger
            #   s2 => middle finger
            #   s3 => ring finger
            #   s4 => pinky finger
            s1,s2,s3,s4 = recv_.decode().strip().split(",")
            servos = [
                      int(s1),
                      int(s2),
                      int(s3),
                      int(s4)
                    ]
                        
            control(servos)


if __name__ == "__main__":
    i2c = busio.I2C(board.SCL, board.SDA)
    pca = PCA9685(i2c)
    kit = ServoKit(channels=16)

    servo = init_servos(4)
    connect()

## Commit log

2025-09-05 added autoformatter in requirements.txt, formatted main.py and new function write_to_sd(), modified shell script to check sdcard mount
2025-09-09 added alternative USB HUB option, modified gps_task() to ignore checksum error and printing info to output, added comprehensive comments to functions and shell script
    [main.py]
2025-09-18 added nixos data analysis content: new analysis directory, outdoor testing picture, new README, duckdb database, and jupyter notebook. fixed main.py to write headers onto csv file, rearrange image di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
    [main.py]
2025-09-18 modified main.py to include datetime for easier data analysis, renamed cyberdeck_analysis to sample_cyberdeck_analysis, added more examples to analysis file
2025-09-22 renamed and modified ipynb file to add more examples, added more image samples, changes to duckdb database to simplify usage
2025-09-22 Revert "renamed and modified ipynb file to add more examples, added more image samples, changes to duckdb database to simplify usage"
    This reverts commit 418cfabd58e88ee1db71321f4538c8c3d6c8d7bb.
2025-10-07 revised schematic drawings, added architectural diagrams for cyberdeck and nixexp, made demo.mp4 to demo.gif to properly display on desktop, also fixed a typo
2025-11-06 added esp32 glove sensor directory and documents
2025-11-25 added Applications section for esp32 glove and included Servo Controller
2025-11-25 Revise headings and content in README.md for ESP32 Glove
    Updated README.md to improve section headings and formatting.
2026-07-10 added kicad schematic and case enclosure for cyberdeck
2026-07-10 added kicad schematic and case enclosure picture for cyberdeck
2026-07-11 updated kicad schematic to include external gps module and usb ftdi
2026-07-13 corrected wrong pinouts for GPS and made FTDI a connector for schematic
2026-07-18 added new directory called CAD (Computer Aided Design) for hardware designs
    [V1_nixos_cyberdeck.FCStd, V1_nixos_cyberdeck.kicad_sch, V1_nixos_cyberdeck.stl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]
2026-07-18 reuploaded correct schematic preview image for cad v1
2026-07-18 reverted main README schematic image to original
